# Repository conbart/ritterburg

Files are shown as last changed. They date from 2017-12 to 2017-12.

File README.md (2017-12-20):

# Ritterburg Bastelprojekt

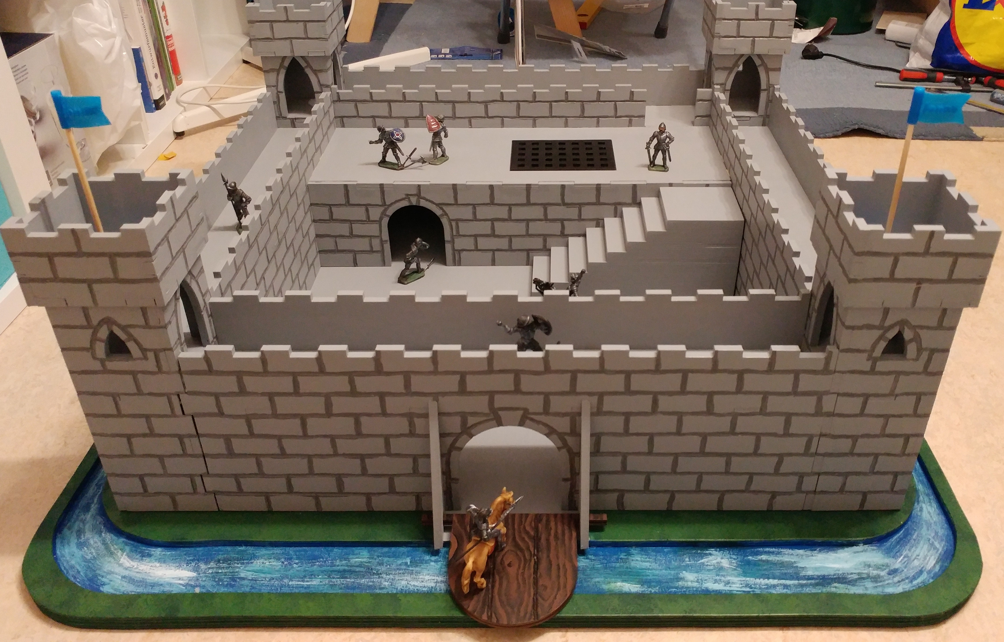
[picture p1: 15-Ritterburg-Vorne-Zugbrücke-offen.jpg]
Frontansicht der Ritterburg mit offener Zugbrücke

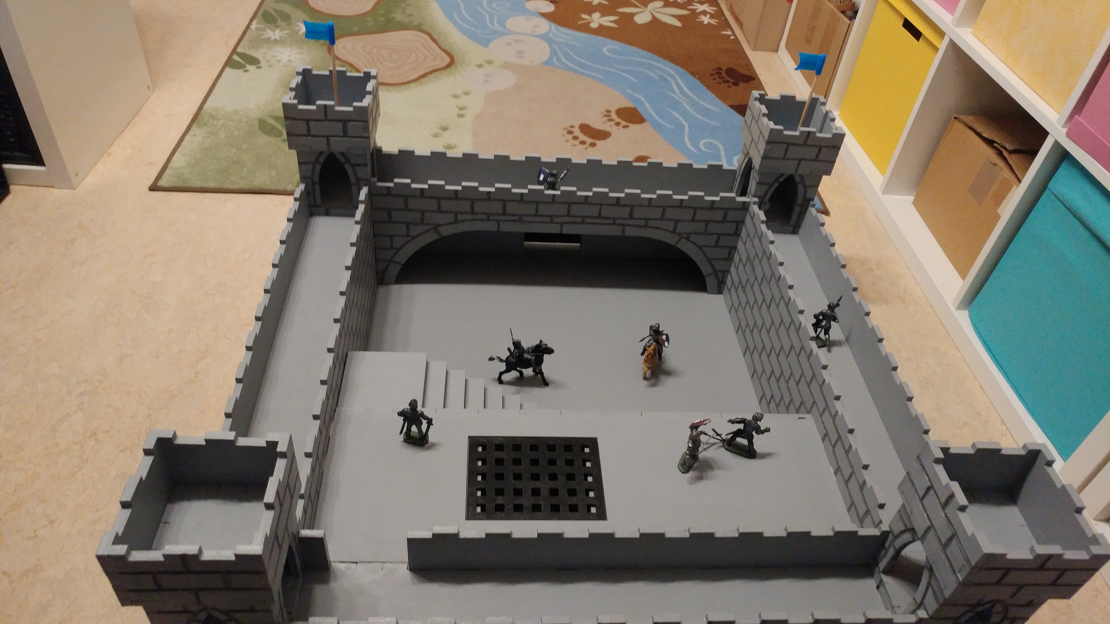
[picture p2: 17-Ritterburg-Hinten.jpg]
Rückansicht der Ritterburg


## Arbeitsschritte

- Erstellen eines 3D-Modell der Burg für 8mm und 4mm Pappelsperrholz in OpenSCAD
- Erstellen einer 2D Projektion der Teile ebenfalls in OpenSCAD und exportieren zu SVG
- Nachbearbeitung der SVG Datei mit Inkscape und Aufteilung in einzelne Dateien für verschiedene Bretter
- Exportieren der SVG Dateien als DXF
- Ausschneiden der DXF Dateien (bis auf Bodenplatten, da zu groß) mit Lasercutter des Fablabs-Neckar-Alb: Radium Laser Model 1390
- Säubern der Bretter von den Ascheresten vom Schneiden
- Vorzeichnen eines Backsteinmusters mit Lineal und Bleistift auf die Bretter
- Fräsen eines Backsteinmusters mit Dremel 3000
- Abschleifen der Bretter mit Sandpapier
- Verkleben von Teilen mit Holzleim zu größeren Einheiten, wie Türmen, Außenmauern etc.
- Lackieren der Teile (Grundfarbe) mit Acryllack
- Teilweise lackieren der Details mit Acryllack
- Design des Flaggensockels mit OpenSCAD und Export als STL
- Design der Flagge mit Blender und Export als STL
- Vorbereiten des 3D Drucks der Flaggenteile mit slic3r
- 3D Druck der Flaggenteile mit CT'c Replicator 2 Clone des Fablabs-Neckar-Alb
- Erstellen der Flaggen aus Flaggenteilen und Blumenstäben
- Bemalen von Details mit Acryllack
- Verkleben der größeren Einheiten zu einer Burg
- Nachbessern der Lackierungen an den Klebestellen
- Plotten einer Schablone für die Bodenplatten mit Din A0 Plotter
- Sägen der Bodenplatten mit Stichsäge im Fablab-Neckar-Alb
- Abschleifen der Bodenplattenränder mit Sandpapier
- Verkleben der Bodenplatten
- Bemalen der Bodenplatten mit Acryllack
- Löten und Basteln der Beleuchtungseinheit
- Befestigen der Beleuchtungseinheit in der Burg mit Klettband
- Kleben von Holzklötzen in die Türme um die Bodenplatte daran befestigen zu können
- Befestigen der Burg und der Treppe an den Bodenplatten mit Holzschrauben

www.fablab-neckar-alb.org

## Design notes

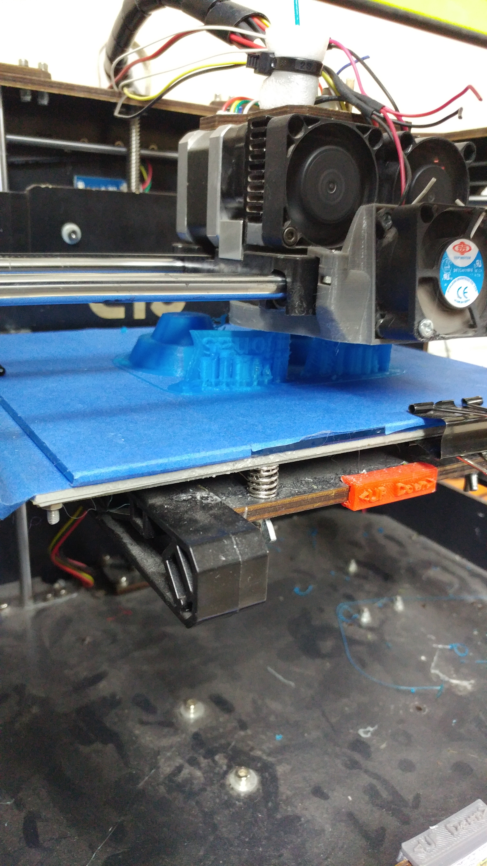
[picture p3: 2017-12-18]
06-3D-Drucker.jpg

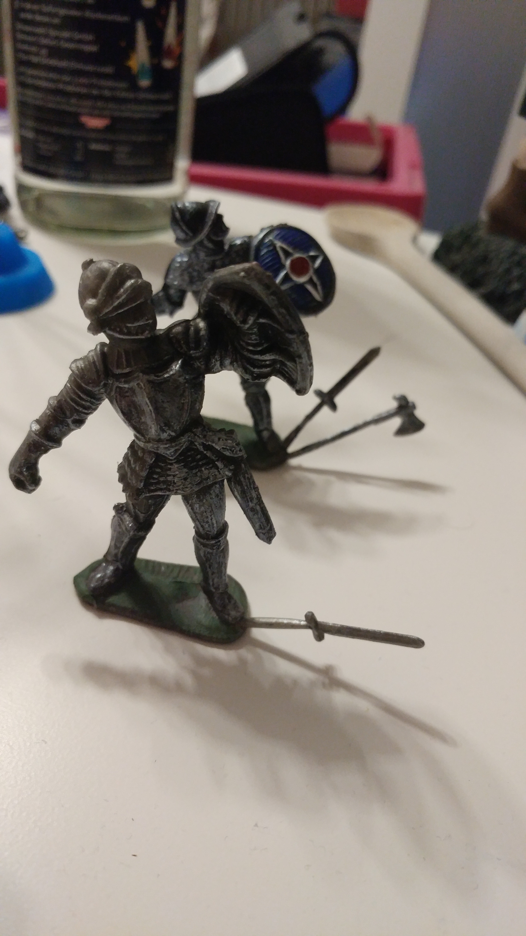
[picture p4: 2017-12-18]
11-Ritter.jpg

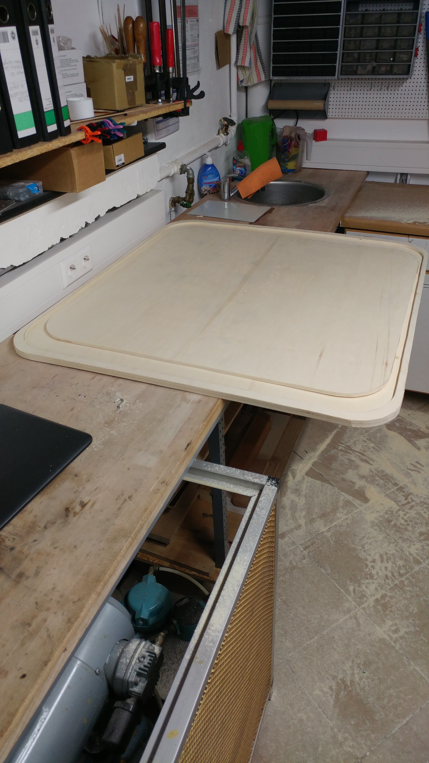
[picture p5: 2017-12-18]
12-Bodenplatte.jpg

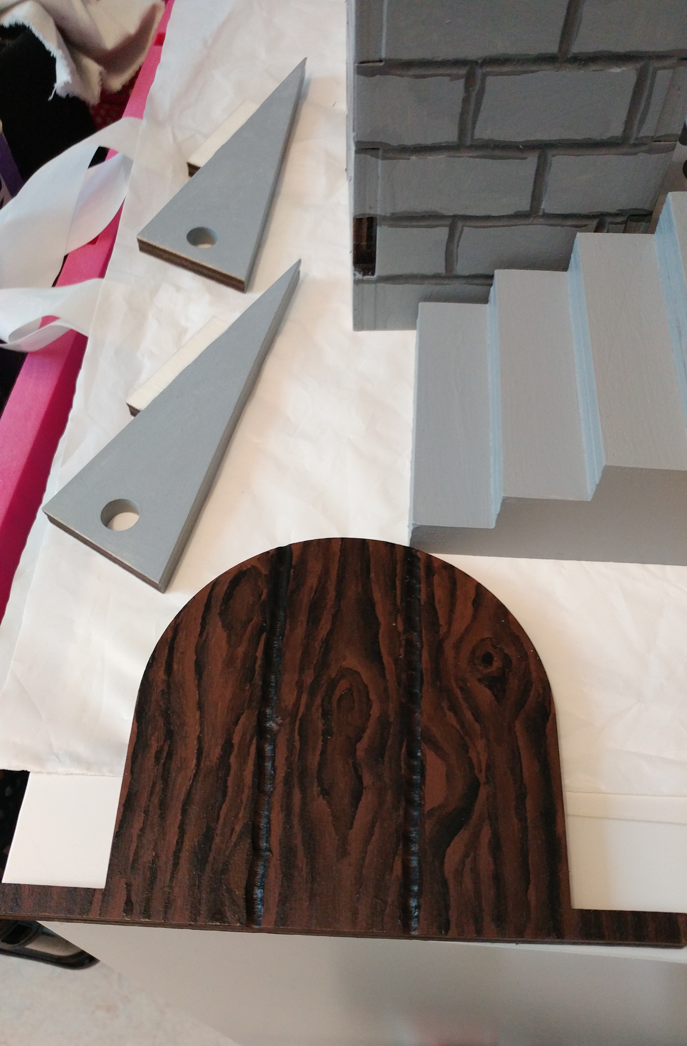
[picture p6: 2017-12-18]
10-Zugbrücke.jpg

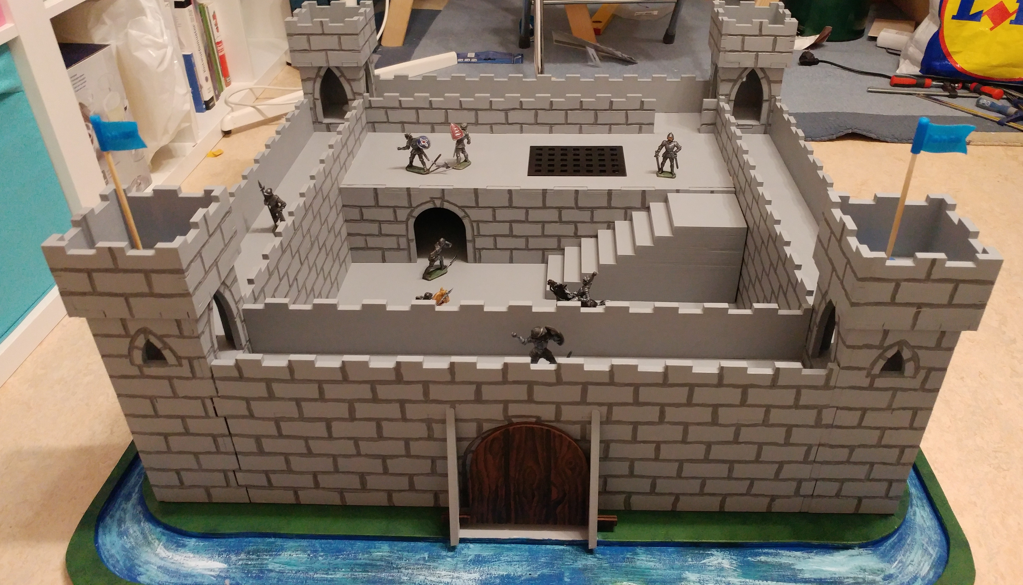
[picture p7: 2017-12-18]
16-Ritterburg-Vorne-Zugbrücke-geschlossen.jpg

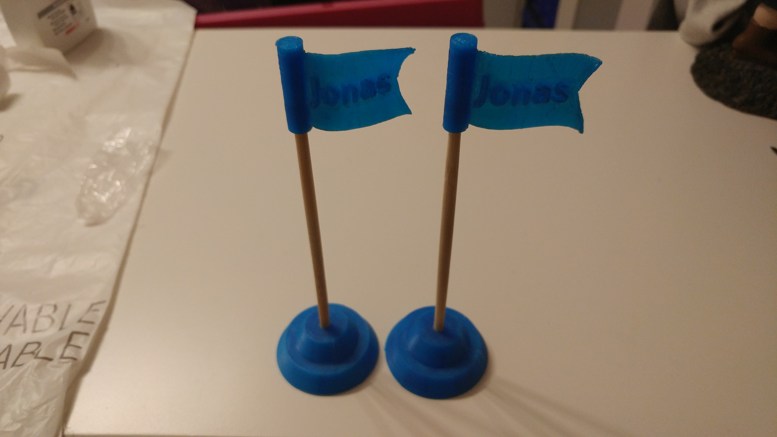
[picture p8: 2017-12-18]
08-Flaggen.jpg

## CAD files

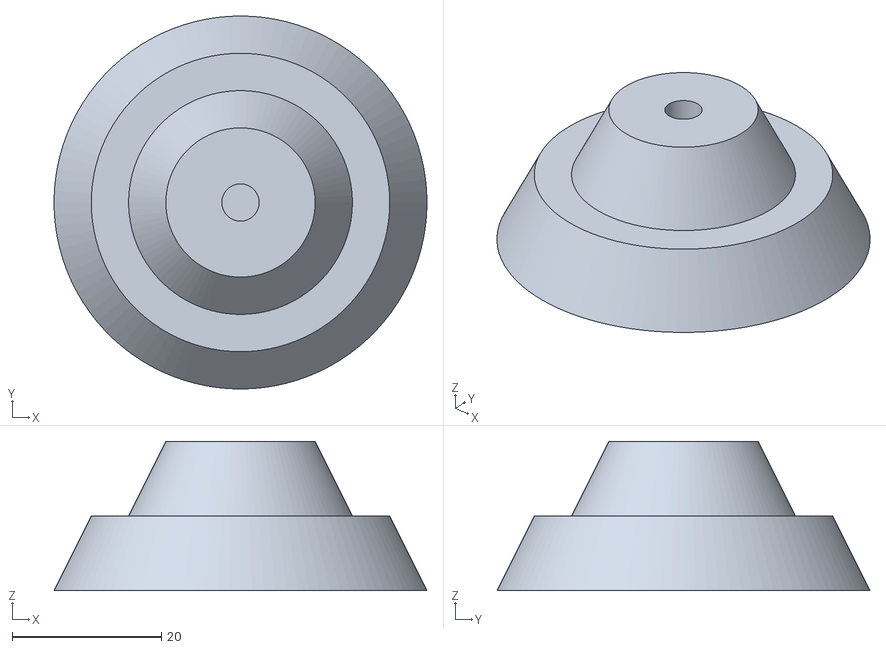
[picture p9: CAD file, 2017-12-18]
Sockel.stl
50.0 x 50.0 x 20.0

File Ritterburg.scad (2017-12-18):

// x = breite
// y = tiefe
// z = hoehe

dicke=8;
hdicke=dicke/2;
rmdicke=dicke+2;
rm1sdicke=dicke+1;
rmhdicke=rmdicke/2;
unit=25;
hunit=unit/2;
$fn=100;

// turmseite
tsbreite=100;
tstiefe=dicke;
tshoehe=250;

// turmplatte
tpbreite=tsbreite;
tptiefe=tsbreite;
tphoehe=dicke;

// turmetage
tebreite=tsbreite-2*dicke;
tetiefe=tsbreite-2*dicke;
tehoehe=dicke;

// turmkrone
tkbreite=tpbreite+2*dicke;
tktiefe=dicke;
tkhoehe=3*unit;

//turmfenster
tfgroesse=3;
tfhoehe=190;

//turmtuer
ttgroesse=6;
tthoehe=6*unit;

// turm
tmbreite=tkbreite;
tmtiefe=tkbreite;
tmhoehe=tshoehe+tkhoehe;

// burg
bgbreite=800;
bgtiefe=800;
bghoehe=tmhoehe;


//aussenmauerseite
amsbreite=bgbreite-(2*tkbreite)+(2*dicke);
amstiefe=dicke;
amshoehe=tthoehe+2*unit;

//aussenmauerweg
amwbreite=amsbreite;
amwtiefe=tsbreite-(2*dicke);
amwhoehe=5*unit;

//aussenmauer
ambreite=amsbreite;
amtiefe=tsbreite;
amhoehe=amshoehe;

//hausdach
hdbreite=ambreite;
hdtiefe=ambreite/3;
hdhoehe=amwhoehe;

//hausmauer
hmbreite=ambreite;
hmtiefe=dicke;
hmhoehe=amwhoehe+dicke;

//treppe
trbreite=11*unit;
trtiefe=4*unit;
trhoehe=8*dicke;

//zugbruecke
zbbreite=140;
zbtiefe=dicke/2;
zbhoehe=130;

//turmfenster
module turmfenster(x=0,y=0,z=0,rot=0,groesse=0){
    // grundform
    translate([x,y,z])translate([0,(rmdicke/2),0])rotate([90,0,0])intersection(){
        translate([groesse*11,0,0])cylinder(d=groesse*30,h=rmdicke);
        translate([-groesse*11,0,0])cylinder(d=groesse*30,h=rmdicke);
        translate([0,groesse*15,(rmdicke/2)])cube([groesse*30,groesse*30,rmdicke],center=true);
    }
}

//turmtuer
module turmtuer(x=0,y=0,z=0,rot=0,groesse=0){
    translate([x,y,z])translate([0,(rmdicke/2),groesse*6-1])rotate([90,0,0])union(){
        // grunform
        intersection(){
            translate([groesse*11,0,0])cylinder(d=groesse*30,h=rmdicke);
            translate([-groesse*11,0,0])cylinder(d=groesse*30,h=rmdicke);
            translate([0,groesse*15,(rmdicke/2)])cube([groesse*30,groesse*30,rmdicke],center=true);
        }
        // verlaengerung unten
        translate([0,-groesse*3+1,(rmdicke/2)])cube([groesse*8,groesse*6,rmdicke],center=true);
    }
}

// turmseite
module turmseite(x=0,y=0,z=0,rot=0,aussen=false,special=false){
    breite=tsbreite;    
    hoehe=tshoehe;
    hhoehe=hoehe/2;
    hbreite=breite/2;
    translate([x,y,z])translate([0,0,hhoehe])rotate(rot){
        difference(){
            translate([-hbreite,-hdicke,-hhoehe])union(){
                difference(){
                    // grundform
                    cube([breite,dicke,hoehe]);
                    if (aussen){
                        if (special){
                            // ausschnitte links
                            translate([-1,-1,-1])cube([rm1sdicke,rmdicke,(unit*3)+1]);  
                            translate([-1,-1,4*unit])cube([rm1sdicke,rmdicke,unit*3]);         
                            translate([-1,-1,8*unit])cube([rm1sdicke,rmdicke,unit]);                    }
                        else {
                            // ausschnitte links
                            translate([-1,-1,-1])cube([rm1sdicke,rmdicke,unit+1]);
                            translate([-1,-1,2*unit])cube([rm1sdicke,rmdicke,unit]);  
                            translate([-1,-1,4*unit])cube([rm1sdicke,rmdicke,unit]);         
                            translate([-1,-1,6*unit])cube([rm1sdicke,rmdicke,unit]); 
                            translate([-1,-1,8*unit])cube([rm1sdicke,rmdicke,unit]);
                        }
                    }
                    else {
                        // ausschnitte links
                        translate([-1,-1,-1])cube([rm1sdicke,rmdicke,(unit*3)+1]);
                        translate([-1,-1,4*unit])cube([rm1sdicke,rmdicke,unit*3]);          
                        translate([-1,-1,8*unit])cube([rm1sdicke,rmdicke,unit]);
                    }
                    // ausschnitte rechts 
                    translate([breite-dicke,-1,1*unit])cube([rm1sdicke,rmdicke,unit]);
                    translate([breite-dicke,-1,3*unit])cube([rm1sdicke,rmdicke,unit]);  
                    translate([breite-dicke,-1,5*unit])cube([rm1sdicke,rmdicke,unit]);  
                    translate([breite-dicke,-1,7*unit])cube([rm1sdicke,rmdicke,unit]);  
                    translate([breite-dicke,-1,9*unit])cube([rm1sdicke,rmdicke,unit+1]);
                }
                // nut oben 
                translate([(breite-unit)/2,0,hoehe])cube([unit,dicke,dicke]);
            }
            translate([-hbreite,-hdicke,-hhoehe]){
                if(aussen==true){
                    turmfenster(hbreite,hdicke,tfhoehe,0,tfgroesse);
                    translate([hbreite-(unit/2),hdicke-(rmdicke/2),tthoehe-dicke])cube([unit,rmdicke,dicke]);             
                }
                else {
                    turmtuer(hbreite,hdicke,tthoehe,0,ttgroesse);
                    // ausschnitte fuer turmetage
                    translate([hbreite-hunit,hdicke-(rmdicke/2),tthoehe-dicke])cube([unit,rmdicke,rm1sdicke]);
                    // ausschnitte fuer mauer 
                    translate([hbreite-(unit/2),hdicke-(rmdicke/2),amwhoehe])cube([unit,rmdicke,dicke]);        
                }       
            }
        }

    }
 
}

// turmetage
module turmetage(x=0,y=0,z=0,rot=0){
    breite=tebreite;
    tiefe=tetiefe;      
    hoehe=tehoehe;  
    hhoehe=hoehe/2;
    htiefe=tiefe/2;
    hbreite=breite/2;
    translate([x,y,z])translate([0,0,hhoehe])rotate(rot)translate([-hbreite,-htiefe,-hhoehe])union(){
        // grundform
        cube([breite,tiefe,hoehe]);      
        // nut seitlich
        translate([((breite-unit)/2),-dicke,0])cube([unit,dicke,hoehe]);
        translate([((breite-unit)/2),tiefe,0])cube([unit,dicke,hoehe]);
        translate([-dicke,((breite-unit)/2),0])cube([dicke,unit,hoehe]);
        translate([tiefe,((breite-unit)/2),0])cube([dicke,unit,hoehe]);       
    }
}


// turmplatte
module turmplatte(x=0,y=0,z=0,rot=0){
    breite=tpbreite;
    tiefe=tptiefe;      
    hoehe=tphoehe;  
    hhoehe=hoehe/2;
    htiefe=tiefe/2;
    hbreite=breite/2;
    translate([x,y,z])translate([0,0,hhoehe])rotate(rot)translate([-hbreite,-htiefe,-hhoehe])union(){
        difference(){
            // grundform
            cube([breite,tiefe,hoehe]);
            // ausschnitte befestigung unten
            translate([(breite-unit)/2,-1,-1])cube([unit,rm1sdicke,rmdicke]);      
            translate([(breite-unit)/2,tsbreite-dicke,-1])cube([unit,rm1sdicke,rmdicke]);
            translate([tsbreite-dicke,(breite-unit)/2,-1])cube([rm1sdicke,unit,rmdicke]);
            translate([-1,(breite-unit)/2,-1])cube([rm1sdicke,unit,rmdicke]);       
        }
        // nut seitlich
        translate([0,-dicke,0])cube([unit,dicke,hoehe]);
        translate([breite-unit,-dicke,0])cube([unit,dicke,hoehe]);
        translate([0,tiefe,0])cube([unit,dicke,hoehe]);
        translate([breite-unit,tiefe,0])cube([unit,dicke,hoehe]);
        translate([-dicke,0,0])cube([dicke,unit,hoehe]);
        translate([-dicke,breite-unit,0])cube([dicke,unit,hoehe]);
        translate([tiefe,0,0])cube([dicke,unit,hoehe]);
        translate([tiefe,breite-unit,0])cube([dicke,unit,hoehe]);         
    }
}

// turmkrone
module turmkrone(x=0,y=0,z=0,rot=0){
    breite=tkbreite;
    tiefe=tktiefe;      
    hoehe=tkhoehe;  
    hhoehe=hoehe/2;
    htiefe=tiefe/2;
    hbreite=breite/2;
    translate([x,y,z])translate([0,0,hhoehe])rotate(rot)translate([-hbreite,-htiefe,-hhoehe])difference(){
        // grundform
        cube([breite,tiefe,hoehe]);
        // ausschnitte befestigung unten
        translate([dicke-1,-1,-1])cube([unit+1,rmdicke,rm1sdicke]);
        translate([breite-unit-dicke,-1,-1])cube([unit,rmdicke,rm1sdicke]); 
        // ausschnitte befestigung seitlich
        translate([-1,-1,-1])cube([rm1sdicke,rmdicke,unit+(hunit/2)+1]);  
        translate([-1,-1,unit+hunit+(hunit/2)])cube([rm1sdicke,rmdicke,unit+(hunit/2)+1]);
        translate([breite-dicke,-1,unit+(hunit/2)])cube([rm1sdicke,rmdicke,hunit]); 
         // ausschnitte oben
        translate([((breite-unit)/2)-unit,-1,hoehe-dicke])cube([unit,rmdicke,rm1sdicke]);
        translate([((breite-unit)/2)+unit,-1,hoehe-dicke])cube([unit,rmdicke,rm1sdicke]);        
    }
    
}
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

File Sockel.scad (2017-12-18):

$fn=100;
difference(){
    union(){
        translate([0,0,0])cylinder(r1=25,r2=20,h=10);
        translate([0,0,10])cylinder(r1=15,r2=10,h=10);
    }
    translate([0,0,5])cylinder(r1=2.5,r2=2.5,h=20);
}
